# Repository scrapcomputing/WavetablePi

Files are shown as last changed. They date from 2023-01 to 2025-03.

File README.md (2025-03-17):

# WavetablePi

WavetablePi is a wavetable module based on the Raspberry Pi Zero 2 W running [mt32-pi](https://github.com/dwhinham/mt32-pi).
It is capable of emulating several midi synthesizers, including mt32, sc55 and general midi with custom sound fonts.
For a complete feature list please refer to the [mt32-pi](https://github.com/dwhinham/mt32-pi) project.

For controlling the mt32-pi from DOS, please use [mt32-pi-control](https://github.com/gmcn42/mt32-pi-control).

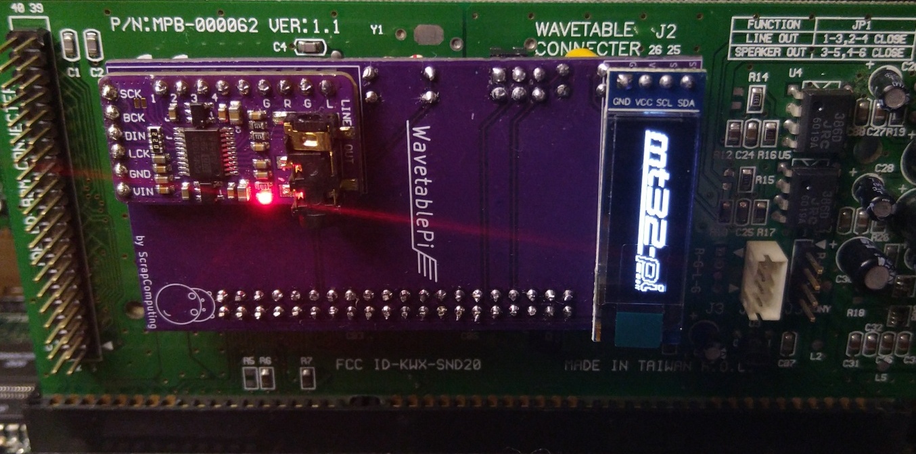
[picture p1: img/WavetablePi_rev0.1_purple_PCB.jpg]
WavetablePi with OLED Display and DAC

<p float="left">
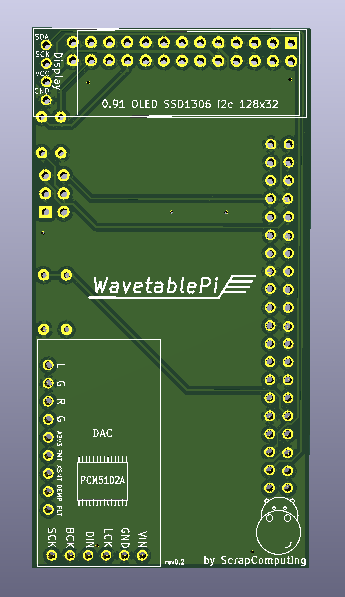
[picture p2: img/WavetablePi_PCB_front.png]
WavetablePi PCB Front

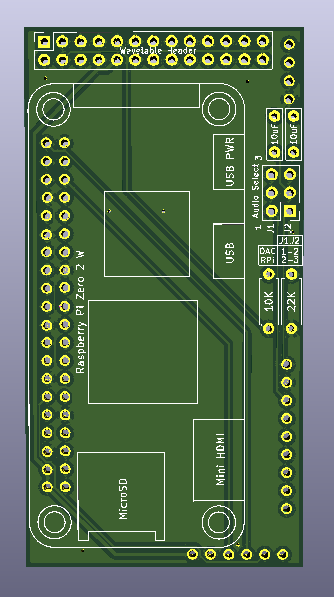
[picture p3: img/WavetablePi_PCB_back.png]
WavetablePi PCB Back

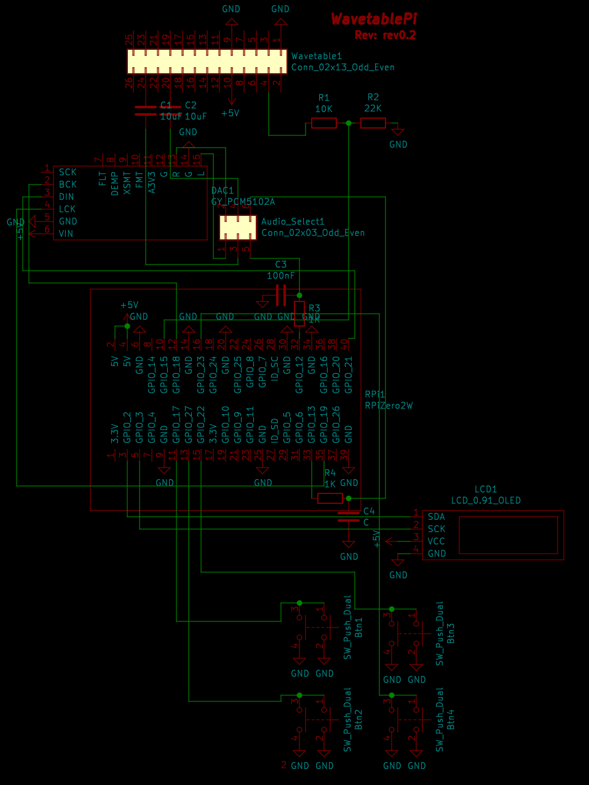
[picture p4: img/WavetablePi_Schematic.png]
WavetablePi Schematic

</p>

- For the "Horizontal" version of this board please check out [WavetablePiHoriz](https://github.com/scrapcomputing/WavetablePiHoriz).

# Features

- It currently supports two modes of audio: using the raspberry pi's PWM audio out (which is noisy and sounds pretty bad), and an external Hi-Fi PCM5102A based DAC.
- You can also attach a 0.91 OLED SSD1306 I2C 128x32 display.
- Starting from rev 0.3 PWM audio is filtered by a simple low-pass filter (R3-C3 and R4-C4).

# I want to build one myself!
- Please note that the current version of the WavetablePi board is quite tall (76mm x 40mm) so please check if it fits your sound card, especially if it needs to be placed perpendicularly to the ISA slots.
- Also please make sure that there is enough clearance between the WavetablePi and the sound card. Some cards have large components that may touch the raspberry pi a
- A WavetablePi with the DAC or the OLED display takes quite a bit of vertical space, so you will end up wasting one ISA slot! There is just no room for a card right next to the sound card, as the OLED display and the DAC will be in the way.
- Finally please check that the PCM5102A HiFi DAC is in the form factor that fits the board. The one I am using is approximately 32mm x 17mm. Also please check that the pinout matches.
- For ordering the PCB, you usually just need to upload the zipped [gerber files](https://github.com/scrapcomputing/WavetablePi/releases/download/rev0.3/WavetablePi_gerbers_rev0.3.zip) to the fab's website.

# Assembly Tips / Troubleshooting
- For attaching the Pi flush against the board, it may be better to cut the 40-pin header into short sections (like 2x3) before soldering them. This should make it easier to solder and to remove the plastic spacers after soldering.
- DAC Board: Before soldering, check if the address solder bridges on the back are set: https://github.com/dwhinham/mt32-pi/wiki/GY-PCM5102-DAC-module
- If the music sounds weird, or slow check `mt32-pi.cfg`. You may need to set `gpio_baud_rate = 31250`.
- Please check out the detailed documentation of the mt32-pi project: https://github.com/dwhinham/mt32-pi

These tips are based on feedback from [ThatRed](https://github.com/ThatRed) (many thanks!). Feel free to check out the full text: https://github.com/scrapcomputing/WavetablePi/issues/1

# Videos
- [Original Wavetable-Pi video](https://www.youtube.com/watch?v=xC-qhcPUeRs)
- [PWM audio improvements](https://www.youtube.com/watch?v=HqzHcLejGF4)
- [Awesome video by Bits und Bolts](https://www.youtube.com/watch?v=s2xgwXyD_c8)

# Bill of materials

Item                                     | #   | Description
-----------------------------------------|-----|-----------------------------------------
Raspberry Pi Zero 2 W                    | 1   | The older RPi Zero is not fast enough
40-pin 2x20 male header 2.54mm pitch     | 1   | For attaching the RPi to the board.
26-pin 2x13 female header 2.54mm pitch   | 1   | For attaching the board to the wavetable header
6-pin 2x3 pin male header 2.54mm pitch   | 1   | For the audio select jumpers
Jumper 2.54mm pitch                      | 2   | Jumpers for the audio selection header
Capacitor 10uF through-hole ceramic      | 2   |
Capacitor 100nF through-hole ceramic     | 2   | C3 and C4 which form the PWM audio low-pass filter along with R3 and R4. 100nF is for a 1.6KHz cutoff frequency. Use lower values for higher cutoff
Resistor 22K Ohm                         | 1   |
Resistor 10K Ohm                         | 1   |
Resistor 1K Ohm                          | 2   | R3 and R4, which along with C3 and C4 form a low-pass filter of the PWM audio
0.91 OLED SSD1306 I2C 128x32 module      | 1   | (Optional)
PCM5102A I2S DAC Module (aka GY PCM5120) | 1   | (Optional but highly recommended) Please check the PCB for the supported dimensions and form factor!

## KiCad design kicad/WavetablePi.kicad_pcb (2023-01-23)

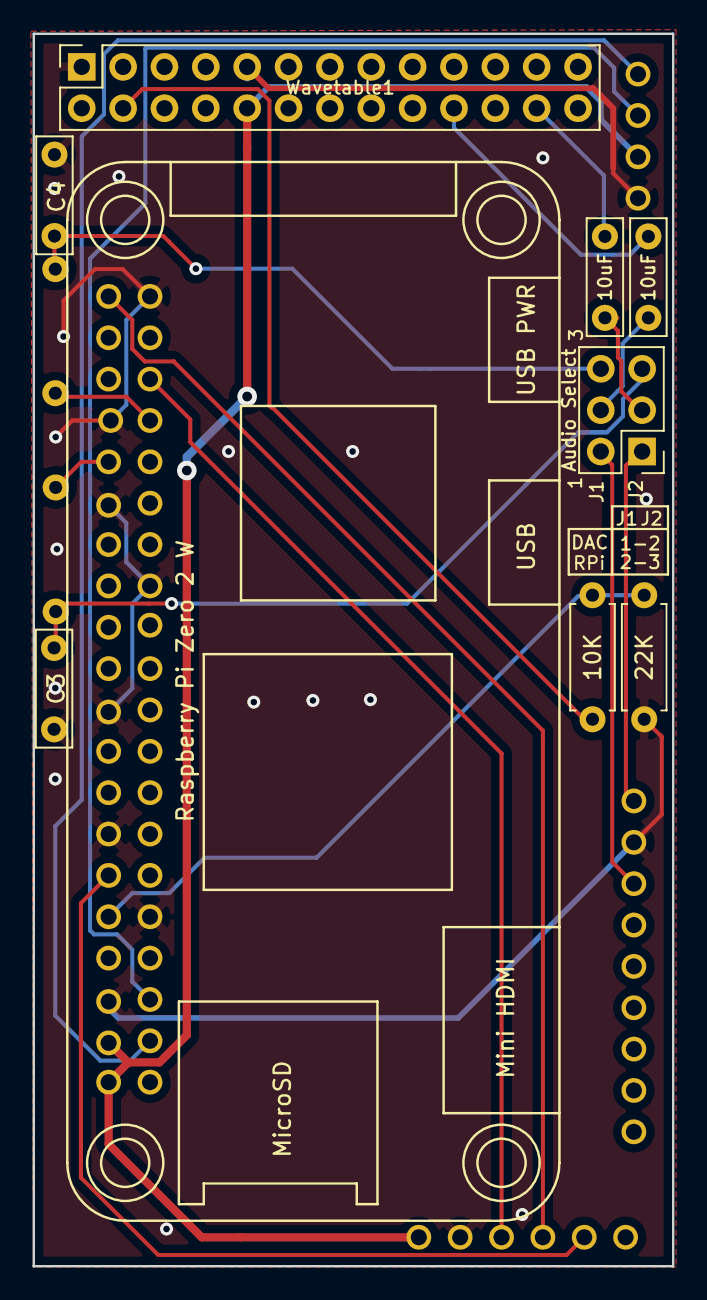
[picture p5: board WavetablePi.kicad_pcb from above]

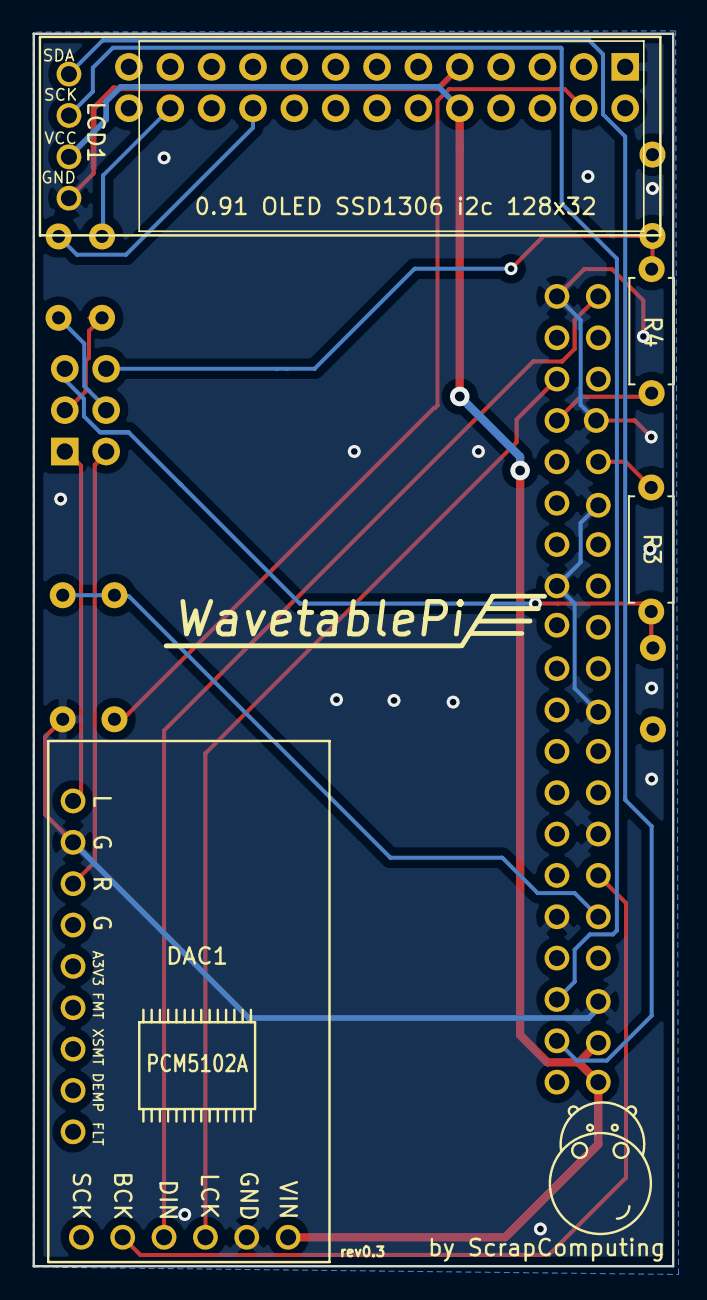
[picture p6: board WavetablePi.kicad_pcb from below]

Board: 2 copper layers, 39.3 x 75.7 mm, 13 parts (4 on the bottom side), 19 nets.

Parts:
10K: 10K; R_Axial_DIN0207_L6.3mm_D2.5mm_P7.62mm_Horizontal
10uF, 10uF#2: 10uF; C_Rect_L7.0mm_W2.0mm_P5.00mm
22K: 22K; R_Axial_DIN0207_L6.3mm_D2.5mm_P7.62mm_Horizontal
Audio Select: Conn_02x03_Odd_Even; PinHeader_2x03_P2.54mm_Vertical
C3: 100nF; C_Rect_L7.0mm_W2.0mm_P5.00mm
C4: C; C_Rect_L7.0mm_W2.0mm_P5.00mm
DAC1: GY_PCM5102A
LCD1: LCD_0.91_OLED
R3, R4: 1K; R_Axial_DIN0207_L6.3mm_D2.5mm_P7.62mm_Horizontal
Raspberry Pi Zero 2 W: RPiZero2W
Wavetable1: Conn_02x13_Odd_Even; PinSocket_2x13_P2.54mm_Vertical

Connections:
+5V: DAC1.6, LCD1.3, Raspberry Pi Zero 2 W.2, Raspberry Pi Zero 2 W.4, Wavetable1.10
GND: 22K.2, C3.2, C4.2, DAC1.5, DAC1.14, LCD1.4, Raspberry Pi Zero 2 W.6, Raspberry Pi Zero 2 W.9, Raspberry Pi Zero 2 W.14, Raspberry Pi Zero 2 W.20, Raspberry Pi Zero 2 W.25, Raspberry Pi Zero 2 W.30, Raspberry Pi Zero 2 W.34, Raspberry Pi Zero 2 W.39, Wavetable1.1, Wavetable1.9
unnamed: Audio Select.1, DAC1.15
unnamed: Audio Select.2, DAC1.13
unnamed: 10uF.2, Audio Select.3
unnamed: 10uF#2.2, Audio Select.4
unnamed: Audio Select.5, C3.1, R3.1
unnamed: Audio Select.6, C4.1, R4.1
unnamed: 10uF.1, Wavetable1.24
unnamed: 10uF#2.1, Wavetable1.20
unnamed: DAC1.2, Raspberry Pi Zero 2 W.12
unnamed: DAC1.3, Raspberry Pi Zero 2 W.40
unnamed: DAC1.4, Raspberry Pi Zero 2 W.35
unnamed: LCD1.1, Raspberry Pi Zero 2 W.3
unnamed: LCD1.2, Raspberry Pi Zero 2 W.5
unnamed: 10K.1, 22K.1, Raspberry Pi Zero 2 W.10
unnamed: 10K.2, Wavetable1.4
unnamed: R3.2, Raspberry Pi Zero 2 W.32
unnamed: R4.2, Raspberry Pi Zero 2 W.33

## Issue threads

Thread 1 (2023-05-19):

Some tips for building the Wavetable Pi label:documentation

ThatRed, 2023-05-19:
Hi, thank you for your videos! I built one and after some problems it works great!

To make my life a bit easier, I cut the 40 pin header for the Pi every three pins, to get blocks of six, before soldering. I decided to put the longer pins through the pcb and the Pi. If you solder them like in the video, they might not stick fully through and there is a slight chance that some don't make any contact. I started with soldering two blocks of six pins at both ends, than it is pretty easy to remove the plastic and worked my way to the middle.

Before you solder the DAC Board, check if the address solder bridges on the back are set. Mine came with none. You can find a picture of the correct settings on the mt32-pi github page, under wiki, GY PCM5102 DAC module.

After everything is put together and the music sounds weird, slow and you can't send text to your display or reset the mt32-pi, then your hardware probably works, but the mt32-pi settings are wrong. Go to "Midi Options", "gpio_baud_rate" and change it to "31250". To make later changes easier, I configured WiFi and ftp.

If your Pi stopped working after soldering the pin headers, don't panic to much, check the tiny components of the Pi around the pin header for solder bridges. If there is one, be very careful and touch the part for a short amount of time to remove it. I was lucky...

scrapcomputing, 2023-05-20:
Thank you for the tips! I think this will help others build or troubleshoot their WavetablePi.
I updated the Readme file with a summary of your points, and I also linked to your text.
Many thanks!

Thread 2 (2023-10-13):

Are you sure one of the two types of through-hole ceramic capacitors should be 10uF?

msd0smanfred, 2023-10-13:
Like title says, just want to know if that's a typo, since I could easily find all the components except this one in several of the shops I usually frequent, and thinking back I don't think I've ever used a 10uF one either.
Anyway, thank you for sharing this awesome project!

msd0smanfred, 2023-10-13:
Never mind, it all makes sense. It certainly wasn't a typo. Sorry for disturbing.

msd0smanfred, 2023-10-13:
Never mind, I'm sorry I even asked this, I have realized it all makes sense.

Closed 2023-10-13.

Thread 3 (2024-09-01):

Raspberry pi Pico 2 2350? As alternative?

Ripper912, 2024-09-01:
Hi,

Would it be possible to run your project also on Raspberry pi Pico 2 2350 As alternativne?

Thanks

scrapcomputing, 2024-09-03:
This project relies on the mt32-pi project for the software synthesizer, which doesn't work with a Pico / Pico 2 as far as I am aware.

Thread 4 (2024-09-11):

"Thinking" noise in the audio outout

Rawit-git, 2024-09-11:
I've bought one of the units available on Ebay and I've noticed that there is noise in the output. LED and MIDI activity are audable along with a constant ticking sound. With normal listening levels it's not noticeable. It can be heard on the more quite pieces when the listening/recording levels are higher.

Noise almost disappears when the Pi enters power saving mode. The corner where the DAC resides is sensitive to interference as well. Can I fix this? Sorry if this is the wrong place to ask.

scrapcomputing, 2024-09-12:
Hmm I haven't noticed any noise on mine, and this is the first time that someone has raised this issue. Let me check again with some external amplification and I will get back to you.

In the meantime, could it be that it is your sound card that it is somehow picking up this noise ? Have you tried it on a different one?

By the way I was not aware that this is sold on ebay. Getting the boards made by a PCB manufacturer is straightforward, you just upload the gerber zip file and you are done.

Rawit-git, 2024-09-12:
I'm using it in a Terrasoniq Phase X64 external sound card which has a Waveblasterheader. I will try it on my CHiLL III Waveblaster board to see if it makes a difference. I don't hear any noise with a X2GS installed in the Terrasoniq.

I was guessing that you were the seller on Ebay selling extra's but I guessed wrong :/ .

Rawit-git, 2024-09-13:
Same ticking noise on the CHiLL III Waveblaster board. Both the CHiLL III Waveblaster board and the Terrasoniq rely on a 9v power supply. I'm going to test with another power supply later. Both an X2GS and a Yamaha DB51XG don't suffer from noise with this setup.

Rawit-git, 2024-09-13:
The ticking noise only happens in MT-32 mode. In soundfont mode it's more of a whine.

scrapcomputing, 2024-09-14:
Could you try connecting a capacitor on the pins shown in the picture ?
I would try a ceramic 10uF ceramic capacitor, and perhaps a 220uF electrolytic (ground is at the top as shown).
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

Rawit-git, 2024-09-16:
Ok, I will try that when I have time.

Rawit-git, 2024-10-06:
I've installed both a 10uF ceramic capacitor and a 220uF electrolytic capacitor. The ticking noise is gone but it changed to a faint high pitched constant hum.

Rawit-git, 2024-10-06:
In MT32 mode the ticking noise is still present but more faint then before

scrapcomputing, 2024-10-06:
Another thing to try is to feed 5V using a separate wire: Find where 5V is generated on your card and solder a wire between that point and the + of the capacitor you just added. This may get rid of some of the noise.

troydm, 2025-09-16:
There seems to be gnd voltage difference (about 0.5v) between the picogus gnd and dac amplifier gnd output for L and R channels that are fed back to picogus wavetable header, I think this contributes to the noise creating an hearable differnce, probable fix would be to level those to same voltage, but I'm not quite sure how to do it yet

scrapcomputing, 2025-09-16:
> When changing the audio selector jumpers and configuring mt32-pi.cfg to use PWM or I2S, I don't notice any differences.

I am confused. Are you using a DAC module on the wavetable pi or not ?

> If I connect it to an external power supply, even when the PC is off, it still generates the same noise.

I don't understand what you mean. You connected the wavetable pi to an external power supply while the WavetablePi is plugged in to the PicoGus while it's plugged in to an ISA slot. But then how do you get audio output since the PC is off? Doesn't it need power to drive the speakers?

> If the wavetable is connected but has no jumpers set, no noise is heard.

This is expected: The jumpers connect either the DAC or the PWM output to the wavetable "line-in" so if the jumpers are not set then there is no audio coming in.

@troydm The L/R output goes through DC decoupling capacitors, which should explain the voltage difference.

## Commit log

2023-01-16 Initial commit rev0.2
    [WavetablePi.kicad_pcb, WavetablePi.sch]
2023-01-23 Adds a low-pass filter for PWM audio
    Improves the audio quality of PWM audio with a simple low-pass filter.
    This uses R3-C3 and R4-C4 (one filter for each channel).
    [WavetablePi.kicad_pcb, WavetablePi.sch]
2023-01-23 Updated link to gerbers
2023-10-21 Add schematic image
